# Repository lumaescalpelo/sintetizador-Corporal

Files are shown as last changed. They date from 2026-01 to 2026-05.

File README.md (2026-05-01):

# sintetizador-Corporal
Este proyecto contiene el código y modelos para el proyecto de sintetizador corporal.

## Objetivos
El Sintetizador corporal es un proyecto que consiste en un modulo de sensores conectado via WiFi a una PC que convierte las señales recibidas en notas MIDI y un modulo cámara WiFi que envía posiciones skeleton del cuerpo a un programa secundario para mover un modelo 3D.

## Hardware

Cada modulo corporal contiene los siguientes componentes
- 1 micro controlador ESP32 DevKit V1
- 1 sensor de gas MQ-6
- 1 IMU de 9 ejes ICM-20948V2
- 1 Sensor ambiental ENS160 + AHT2X
- 2 Sensor de efecto Hall 49E

- 1 Base Prototipo.stl
- 1 Tapa.stl
- 1 Strap Holder.stl

- 18 tornillos M3x6
- 1 PowerBank 1Hora 5000mAh

Adicionalmente, cada mano cuenta con los siguientes componentes.
- Hand Circuit.stl
- Strap Holder.stl
- Wrist Strap.stl

Para hacer la detección corporal se usa lo siguiente

- 1 ESP32CAM
- Carcasa ESP32CAM

Para realizar las conexiones se requiere:
- 1 WiFi Modem

Para correr el Software se requiere:
- 1 Equipo PC/MAC

### Direcciones I2C

Los sensores cuentan con las siguientes direcciones I2C

```
ENS160 + AHT2X

ENS160
0x52 → ADDR a GND
0x53 → ADDR a VCC

AHT20 / AHT21 (AHT2X)
0x38 → fija, no configurable

ICM-20948

IMU principal
0x68 → AD0 a GND
0x69 → AD0 a VCC

Magnetómetro interno (AK09916)
0x0C
```

## Software

Este proyecto requiere una colección de software necesaria para el funcionamiento de todos sus sistemas. Debido a que puede instalarse en multiples sistemas operativos y plataformas, se enlaza la documentación oficial de cada software. Las pruebas fueron realizadas en Fedora 43. Las versiones de los softwares utilizados se indican en cada etapa.

- [Arduino IDE](https://www.arduino.cc/en/software/). Probado con la versión 2.3.7
- [ESP32 para Arduino IDE](https://docs.espressif.com/projects/arduino-esp32/en/latest/installing.html). Probado con la versón 2.0.18-arduino.5
- [Node.JS](https://nodejs.org/en/download). Probado con la versión 24.13.1 LTS
- [NPM](https://docs.npmjs.com/downloading-and-installing-node-js-and-npm). Probado con la versión 11.8.0
- [Node-Red](https://nodered.org/docs/getting-started/local). Probado con la versión 4.1.5
- [Mosquitto](https://mosquitto.org/download/). Probado con la versión 2.0.22

Consulta cada carpeta correspondiente a cada software para verificar configuraciones específicas.

## Operar el sintetizador

Para operar el sintetizador corporal se deben seguir los siguientes pasos:

- Abrir Símbolo del sistema
- Ejecutar comando node-red
- Abrir localhost:1880 en cualquier navegador
- Contectar todos los equipos a la misma red
- Abrir otro símbolo del sistema
- Ejecutar el comando ipconfig
- Verificar que el flow en node-red tiene la ip del servidor mosquitto
- Si es en la misma computadora debe ser `localhost` o `127.0.0.1`

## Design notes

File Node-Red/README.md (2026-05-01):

# Node-Red

Este documento contiene las instrucciones para la operación de Node-Red.

## Requisitos

- Node.JS
- NPM
- Node-Red

Para iniciar el servidor, ejecuta el comando `node-red` en una terminal y mantén la terminal abierta durante el periodo de operación. Para correr node-red, asegurate de tener el directorio de instalación agregado al path del sistema.

## Nodos externos

Este proyecto necesita los siguientes nodos externos, los cuales puedes descargar gratuitamente en la sección Manage Palette del botón hamburguesa de Node-Red.

- @flowfuse/node-red-dashboard

## Flows

- **01_Lectura_Básica**. Este flow recibe los datos del programa `Full_MQTT_01`.

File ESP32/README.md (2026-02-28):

# ESP32

Este proyeceto hace uso de un ESP32 Devkit V1 para la lectura de los sensores.

## Bibliotecas

Para correr los programas, se requieren las siguientes bibliotecas.

- ArduinoJson de Benoit Blanchon. Versión probrada 7.4.2
- AHTX0 de Adafruit. Versión probada 2.0.5
- Adafruit Unified Sensor de Adafruit. Versión probada 1.1.15
- PubSubClient de Nick O'Leary. Versión probada 2.8

## Programas de prueba

Se realizaron una serie de programas de prueba para verificar progresivamente el funcionamiento de todos los sensores. Antes de probar estos programas, lee completa la lista, pues la lectura del sensor ENS+AHT se corrige hacia el final debido a que se requieren condiciones específicas de lectura.

Los siguientes programas corresponden a la etapa de desarrollo en la que los sensores analogos tienen su propipo pin, y los acelerómetros y el sensor ambiental comparten 2 buses I2C en los pines 21/22 y en los pines 16/17. En esta etapa, las lecturas del ENS+AHT no reportan correctamente valores.

- **Analog Tester**. Es un programa que realiza la lectura de los sensores magnéticos en los `pines 32 y 35` y la lectura del sensor de gases en el  `pin 34`. Los valores se reportan via monitor serial.
- **I2C Lister**. Es un progama que escanea todas las direcciones I2C usando 2 buses para evitar conflictos con las direcciones I2C de los sensores. Se usan 2 buses porque se usan 2 sensores IMU, uno para cada mano. Los buses se encuentran en los `pines 21 y 22` para el bus A y en los `pines 16 y 17` para el bus B.
- **I2C_Reader_0X**. Son programas que realizan la lectura de todos los sensores por diferentes métodos.
- **Full_Reader_01**. Es un programa que realiza la lectura de los sensores analógicos y digitales y reporta todos los valores vía Serial.
- **Full_MQTT_01**. Es un programa que realiza la lectura de todos los sensores y la reporta en un mensaje MQTT separado por comas al tema `sinte/cuerpo1`. Los datos se envían a una IP fija y a una red predeterminada, estos deben actualizarse en caso de cambiar de configuración.

Los siguientes programas corresponden a la etapa de desarrollo en la que se agrega un tercer bus específico para el sensor ENS+AHT en un bus separado en los pines 25/26.

- **ENS_AHT_Tester**. Es un programa que realiza sólo la lectura del sensor ENS+AHT para garantizar su lectura en un tercer bus.
- **Full_MQTT_02**. Este programa realiza la lectura de todos los sensores y corrige el problema de lectura del ENS+AHT que ahora se encuentra en un tercer bus separado. Este cambio se debe a que este sensor requiere condiciones específicas de lectura.
- **Full_MQTT_03**. Este programa envía los valores con punto decimar ajustado para simplificar el envío.

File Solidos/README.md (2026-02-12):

# Solidos

Este documento detalla la información de los solidos necesarios para este proyecto.

Estos son los archivos que dan soporte al dispositivo Sintetizador Corporal. El dispositivo Wearable en realidad solo es un modulo de sensores que recopila información y la envía por OSC, la solución de sonido y la solución de sintetizador pueden ser ajustadas en un equipo PC o Mac donde se reciban los datos.

Cada modulo corporal contiene los siguientes componentes
- 1 micro controlador ESP32 DevKit V1
- 1 sensor de gas MQ-6
- 1 IMU de 9 ejes ICM-20948V2
- 1 Sensor ambiental ENS160 + AHT2X
- 2 Sensor de efecto Hall 49E

- 1 Base Prototipo.stl
- 1 Tapa.stl
- 1 Strap Holder.stl

- 18 tornillos M3x6
- 1 PowerBank 1Hora 5000mAh

Adicionalmente, cada mano cuenta con los siguientes componentes.
- Hand Circuit.stl
- Strap Holder.stl
- Wrist Strap.stl

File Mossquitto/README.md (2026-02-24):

# Mosquitto

Este proyecto usa el broker MQTT Mosquitto para lograr realizar el intercambio de mensajes entre los dispositivos Sintetizador Corporal y los equipos PC/Mac involucrados en el funcionamiento general.

## Configuraciones

Para que un servidor de mosquitto funcione correctamente, debe permitir conexiones desde IPs externas.

Agrega lo siguiente al archivo `/etc/mosquitto/conf.d/remote.conf`

```
allow_anonymous false
listener 1883 0.0.0.0
```

Asegurate de abrir el puerto 1883 para conexiones TCP y UDP.

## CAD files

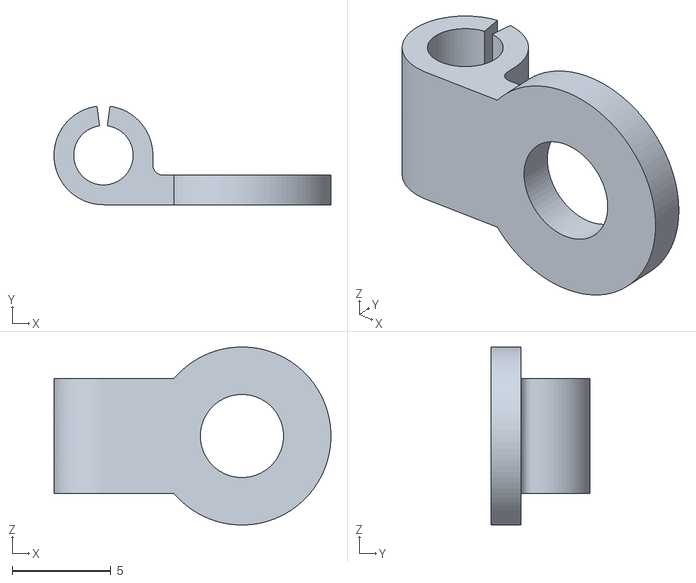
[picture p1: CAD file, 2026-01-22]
Solidos/Clip 2.stl
14.0 x 4.98 x 8.99

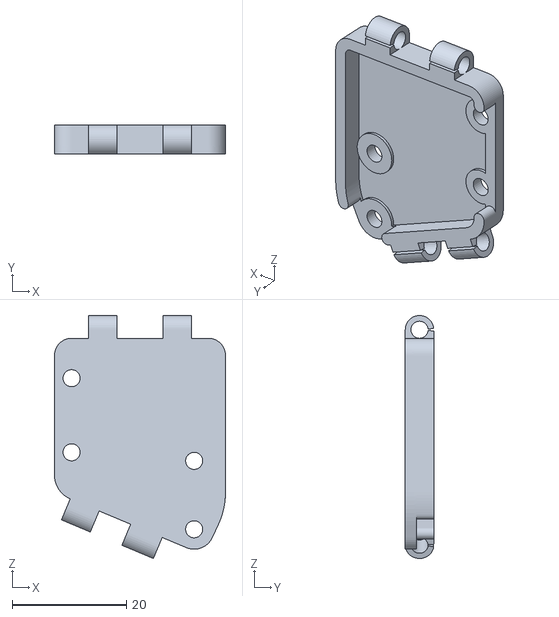
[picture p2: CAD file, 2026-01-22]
Solidos/Hand Circuit.stl
30.0 x 5.00 x 42.6

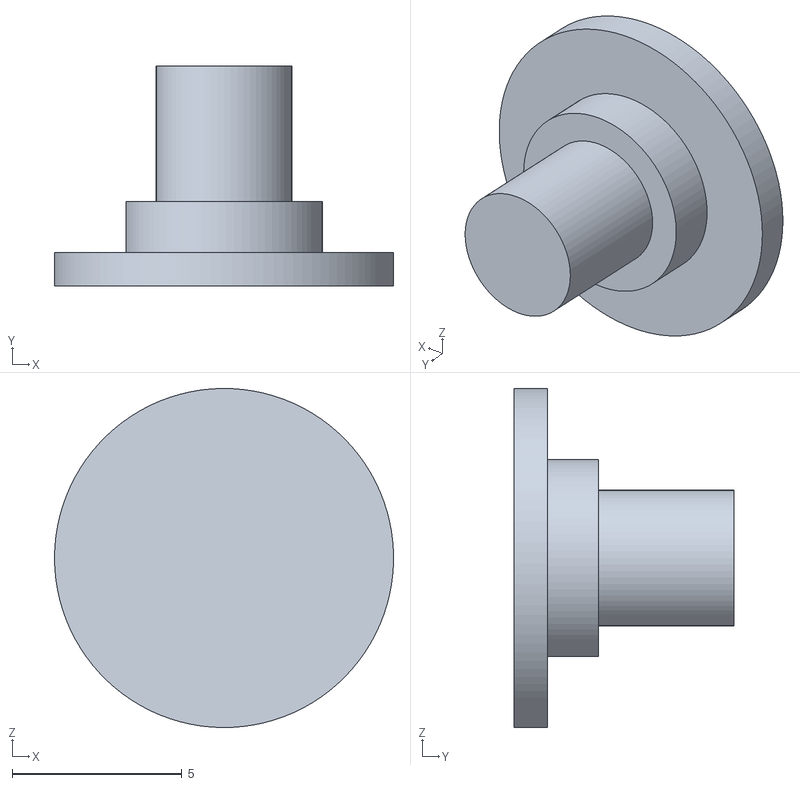
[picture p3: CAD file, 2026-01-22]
Solidos/Clip 1.stl
10.00 x 6.50 x 10.00

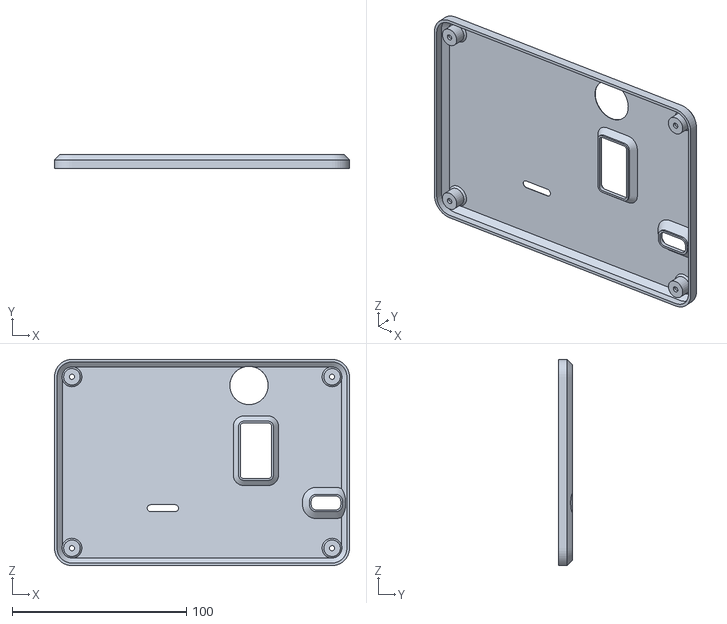
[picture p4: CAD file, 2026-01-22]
Solidos/Tapa.stl
169.5 x 8.00 x 118.5

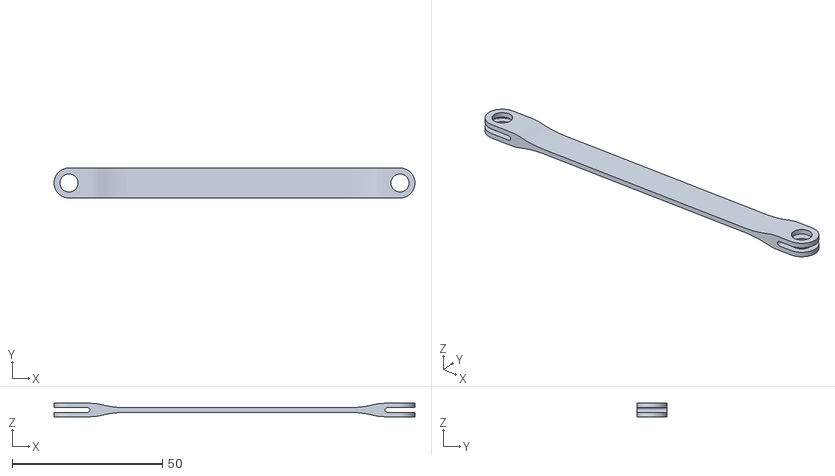
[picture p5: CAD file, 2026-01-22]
Solidos/Wrist Strap.stl
120.0 x 10.0 x 4.50

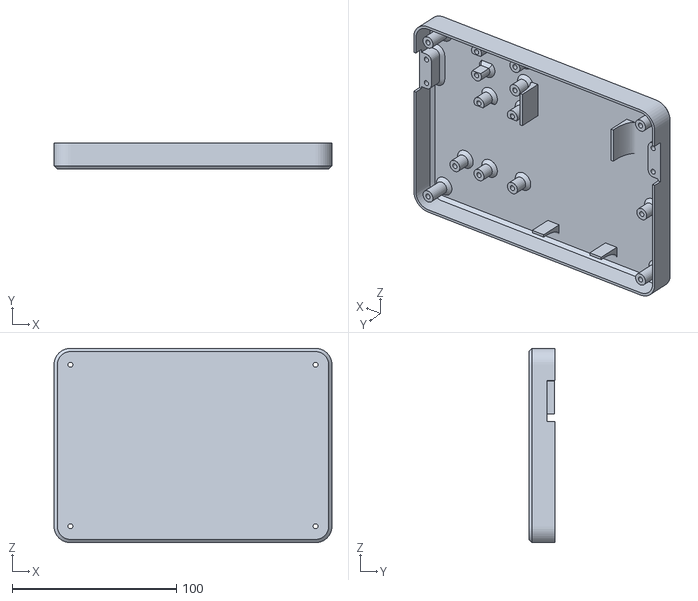
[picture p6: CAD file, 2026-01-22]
Solidos/Base Prototipo.stl
169.5 x 16.0 x 118.5

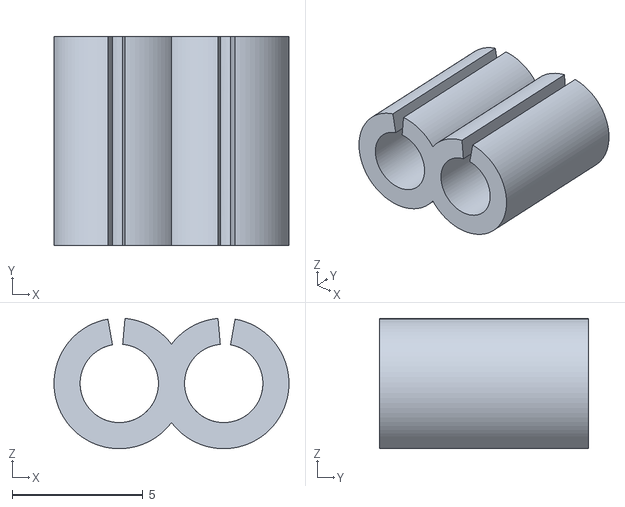
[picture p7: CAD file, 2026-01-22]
Solidos/Strap Holder.stl
9.00 x 8.00 x 4.99

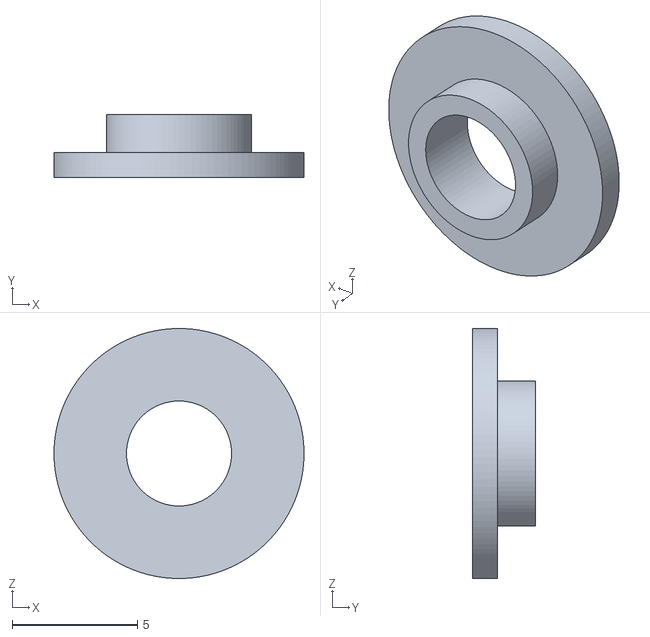
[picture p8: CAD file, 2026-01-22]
Solidos/Clip 3.stl
10.00 x 2.50 x 10.00

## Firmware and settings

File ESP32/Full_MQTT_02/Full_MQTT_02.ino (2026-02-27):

#include <Wire.h>
#include <WiFi.h>
#include <PubSubClient.h>
#include <ArduinoJson.h>

// ================= WiFi / MQTT =================
static const char* WIFI_SSID = "INFINITUMD2AC";
static const char* WIFI_PASS = "PCwGdtcV9D";

static const char* MQTT_HOST = "192.168.1.100";
static const uint16_t MQTT_PORT = 1883;
static const char* MQTT_TOPIC = "sinte/cuerpo1";

WiFiClient espClient;
PubSubClient mqtt(espClient);

// ================= I2C Pines (Hardware) =================
#define SDA_A 21
#define SCL_A 22
#define SDA_B 16
#define SCL_B 17

TwoWire I2C_B = TwoWire(1);

// ================= I2C Pines (Software BUS C) =================
#define SDA_C 25
#define SCL_C 26

// ================= ADC Pines =================
static const int PIN_HALL_32 = 32; // 49E
static const int PIN_MQ6_34  = 34; // MQ-6
static const int PIN_HALL_35 = 35; // 49E

// ================= IMUInfo =================
struct IMUInfo {
  bool present = false;
  bool isMPU6050 = false;
  bool isICM20948 = false;
  uint8_t addr = 0;
};

// ============================================================
//                   Helpers I2C (Hardware)
// ============================================================
bool write8(TwoWire &bus, uint8_t addr, uint8_t reg, uint8_t val) {
  bus.beginTransmission(addr);
  bus.write(reg);
  bus.write(val);
  return bus.endTransmission() == 0;
}

bool readN(TwoWire &bus, uint8_t addr, uint8_t reg, uint8_t *buf, size_t n) {
  bus.beginTransmission(addr);
  bus.write(reg);
  if (bus.endTransmission(false) != 0) return false;
  if (bus.requestFrom((int)addr, (int)n) != (int)n) return false;
  for (size_t i = 0; i < n; i++) buf[i] = bus.read();
  return true;
}

bool read8(TwoWire &bus, uint8_t addr, uint8_t reg, uint8_t &val) {
  return readN(bus, addr, reg, &val, 1);
}

bool ping(TwoWire &bus, uint8_t addr) {
  bus.beginTransmission(addr);
  return (bus.endTransmission() == 0);
}

// ============================================================
//                 Software I2C (BUS C) Bitbang
// ============================================================
// Bitbang súper simple: START/STOP/WRITE/READ con delays.
// Suficiente para AHT2x + ENS160 en bus dedicado.

static inline void i2cDelay() {
  // Ajusta si hace falta: más delay = más confiable (pero más lento)
  delayMicroseconds(6); // ~80-100kHz "aprox" según overhead
}

static inline void sdaHi() { pinMode(SDA_C, INPUT_PULLUP); }
static inline void sdaLo() { pinMode(SDA_C, OUTPUT); digitalWrite(SDA_C, LOW); }

static inline void sclHi() { pinMode(SCL_C, INPUT_PULLUP); }
static inline void sclLo() { pinMode(SCL_C, OUTPUT); digitalWrite(SCL_C, LOW); }

static inline bool sdaRead() { return digitalRead(SDA_C); }

void i2cSoftInit() {
  pinMode(SDA_C, INPUT_PULLUP);
  pinMode(SCL_C, INPUT_PULLUP);
  // idle high
}

void i2cSoftStart() {
  sdaHi(); sclHi(); i2cDelay();
  sdaLo(); i2cDelay();
  sclLo(); i2cDelay();
}

void i2cSoftStop() {
  sdaLo(); i2cDelay();
  sclHi(); i2cDelay();
  sdaHi(); i2cDelay();
}

// Devuelve true si el esclavo ACK
bool i2cSoftWriteByte(uint8_t b) {
  for (int i = 0; i < 8; i++) {
    if (b & 0x80) sdaHi(); else sdaLo();
    i2cDelay();
    sclHi(); i2cDelay();
    sclLo(); i2cDelay();
    b <<= 1;
  }
  // ACK bit
  sdaHi();
  i2cDelay();
  sclHi(); i2cDelay();
  bool ack = (sdaRead() == 0);
  sclLo(); i2cDelay();
  return ack;
}

uint8_t i2cSoftReadByte(bool ack) {
  uint8_t b = 0;
  sdaHi(); // release
  for (int i = 0; i < 8; i++) {
    b <<= 1;
    sclHi(); i2cDelay();
    if (sdaRead()) b |= 1;
    sclLo(); i2cDelay();
  }
  // Send ACK/NACK
  if (ack) sdaLo(); else sdaHi();
  i2cDelay();
  sclHi(); i2cDelay();
  sclLo(); i2cDelay();
  sdaHi();
  return b;
}

bool i2cSoftPing(uint8_t addr7) {
  i2cSoftStart();
  bool ok = i2cSoftWriteByte((addr7 << 1) | 0); // write
  i2cSoftStop();
  return ok;
}

bool i2cSoftWriteReg(uint8_t addr7, uint8_t reg, uint8_t val) {
  i2cSoftStart();
  if (!i2cSoftWriteByte((addr7 << 1) | 0)) { i2cSoftStop(); return false; }
  if (!i2cSoftWriteByte(reg))             { i2cSoftStop(); return false; }
  if (!i2cSoftWriteByte(val))             { i2cSoftStop(); return false; }
  i2cSoftStop();
  return true;
}

bool i2cSoftWriteBytes(uint8_t addr7, const uint8_t *data, size_t n) {
  i2cSoftStart();
  if (!i2cSoftWriteByte((addr7 << 1) | 0)) { i2cSoftStop(); return false; }
  for (size_t i = 0; i < n; i++) {
    if (!i2cSoftWriteByte(data[i])) { i2cSoftStop(); return false; }
  }
  i2cSoftStop();
  return true;
}

bool i2cSoftReadRegN(uint8_t addr7, uint8_t reg, uint8_t *buf, size_t n) {
  i2cSoftStart();
  if (!i2cSoftWriteByte((addr7 << 1) | 0)) { i2cSoftStop(); return false; }
  if (!i2cSoftWriteByte(reg))             { i2cSoftStop(); return false; }

  i2cSoftStart();
  if (!i2cSoftWriteByte((addr7 << 1) | 1)) { i2cSoftStop(); return false; }

  for (size_t i = 0; i < n; i++) {
    buf[i] = i2cSoftReadByte(i + 1 < n); // ACK excepto el último
  }
  i2cSoftStop();
  return true;
}

// ============================================================
//                    AHT2x (BUS C software)
// ============================================================
static const uint8_t AHT_ADDR = 0x38;

bool ahtC_soft_reset() { return i2cSoftWriteReg(AHT_ADDR, 0xBA, 0x00); }

bool ahtC_init() {
  if (!i2cSoftPing(AHT_ADDR)) return false;
  uint8_t cmd[3] = {0xBE, 0x08, 0x00};
  bool ok = i2cSoftWriteBytes(AHT_ADDR, cmd, 3);
  delay(20);
  return ok;
}

bool ahtC_read(float &tempC, float &rh) {
  if (!i2cSoftPing(AHT_ADDR)) return false;

  uint8_t trig[3] = {0xAC, 0x33, 0x00};
  if (!i2cSoftWriteBytes(AHT_ADDR, trig, 3)) return false;

  delay(80);

  uint8_t data[6];
  if (!i2cSoftReadRegN(AHT_ADDR, 0x00, data, 6)) return false;
  if (data[0] & 0x80) return false;

  uint32_t rawHum = ((uint32_t)(data[1]) << 12) | ((uint32_t)(data[2]) << 4) | ((data[3] >> 4) & 0x0F);
  uint32_t rawTmp = ((uint32_t)(data[3] & 0x0F) << 16) | ((uint32_t)(data[4]) << 8) | data[5];

  rh = (rawHum * 100.0f) / 1048576.0f;
  tempC = ((rawTmp * 200.0f) / 1048576.0f) - 50.0f;
  return true;
}

// ============================================================
//                    ENS160 (BUS C software)
// ============================================================
uint8_t ensC_find_addr() {
  if (i2cSoftPing(0x52)) return 0x52;
  if (i2cSoftPing(0x53)) return 0x53;
  return 0x00;
}

bool ensC_init(uint8_t addr) {
  if (!addr) return false;
  // Clear general purpose? (como tu bare-metal)
  i2cSoftWriteReg(addr, 0x12, 0x00);
  delay(20);
  // OPMODE = 0x02 (STANDARD)
  if (!i2cSoftWriteReg(addr, 0x10, 0x02)) return false;
  delay(50);
  return true;
}

bool ensC_read_basic(uint8_t addr, uint8_t &aqi, uint16_t &tvoc, uint16_t &eco2, uint8_t &flags) {
  if (!addr) return false;

  uint8_t b;
  uint8_t buf2[2];

  if (!i2cSoftReadRegN(addr, 0x21, &b, 1)) return false;
  aqi = b;

  if (!i2cSoftReadRegN(addr, 0x22, buf2, 2)) return false;
  tvoc = (uint16_t)buf2[1] << 8 | buf2[0];

  if (!i2cSoftReadRegN(addr, 0x24, buf2, 2)) return false;
  eco2 = (uint16_t)buf2[1] << 8 | buf2[0];

  if (!i2cSoftReadRegN(addr, 0x28, &b, 1)) return false;
  flags = b;

  return true;
}

// ============================================================
//                    MPU-6050 / ICM (hardware)
// ============================================================
bool mpu_init(TwoWire &bus, uint8_t addr) {
  if (!write8(bus, addr, 0x6B, 0x00)) return false;
  delay(10);
  write8(bus, addr, 0x1B, 0x00);
  write8(bus, addr, 0x1C, 0x00);
  return true;
}

bool mpu_read_ag(TwoWire &bus, uint8_t addr, float &ax_g, float &ay_g, float &az_g,
                 float &gx_dps, float &gy_dps, float &gz_dps) {
  uint8_t buf[14];
  if (!readN(bus, addr, 0x3B, buf, 14)) return false;

  int16_t ax = (int16_t)((buf[0] << 8) | buf[1]);
  int16_t ay = (int16_t)((buf[2] << 8) | buf[3]);
  int16_t az = (int16_t)((buf[4] << 8) | buf[5]);
  int16_t gx = (int16_t)((buf[8] << 8) | buf[9]);
  int16_t gy = (int16_t)((buf[10] << 8) | buf[11]);
  int16_t gz = (int16_t)((buf[12] << 8) | buf[13]);

  ax_g = ax / 16384.0f;
  ay_g = ay / 16384.0f;
  az_g = az / 16384.0f;
  gx_dps = gx / 131.0f;
  gy_dps = gy / 131.0f;
  gz_dps = gz / 131.0f;
  return true;
}

bool icm_select_bank(TwoWire &bus, uint8_t addr, uint8_t bank) {
  return write8(bus, addr, 0x7F, (bank << 4));
}

bool icm_init(TwoWire &bus, uint8_t addr) {
  if (!icm_select_bank(bus, addr, 0)) return false;
  write8(bus, addr, 0x06, 0x01);
  delay(10);
  return true;
}

bool icm_read_ag(TwoWire &bus, uint8_t addr, float &ax_g, float &ay_g, float &az_g,
                 float &gx_dps, float &gy_dps, float &gz_dps) {
  if (!icm_select_bank(bus, addr, 0)) return false;
  uint8_t bufA[6], bufG[6];
  if (!readN(bus, addr, 0x2D, bufA, 6)) return false;
  if (!readN(bus, addr, 0x33, bufG, 6)) return false;

  int16_t ax = (int16_t)((bufA[0] << 8) | bufA[1]);
  int16_t ay = (int16_t)((bufA[2] << 8) | bufA[3]);
  int16_t az = (int16_t)((bufA[4] << 8) | bufA[5]);

  int16_t gx = (int16_t)((bufG[0] << 8) | bufG[1]);
  int16_t gy = (int16_t)((bufG[2] << 8) | bufG[3]);
  int16_t gz = (int16_t)((bufG[4] << 8) | bufG[5]);

  ax_g = ax / 16384.0f;
  ay_g = ay / 16384.0f;
  az_g = az / 16384.0f;
  gx_dps = gx / 131.0f;
  gy_dps = gy / 131.0f;
  gz_dps = gz / 131.0f;
  return true;
}

IMUInfo detectIMU(TwoWire &bus, uint8_t addr) {
  IMUInfo info;
  info.addr = addr;

  if (!ping(bus, addr)) return info;

  uint8_t who_mpu;
  if (read8(bus, addr, 0x75, who_mpu)) {
    if (who_mpu == 0x68 || who_mpu == 0x69) {
      info.present = true;
      info.isMPU6050 = true;
      return info;
    }
  }

  uint8_t who_icm;
  if (read8(bus, addr, 0x00, who_icm)) {
    if (who_icm == 0xEA) {
      info.present = true;
      info.isICM20948 = true;
      return info;
    }
  }

  info.present = true; // presente pero desconocido
  return info;
}

// ============================================================
//                    ADC / WiFi / MQTT
// ============================================================
float adc_to_volts(int raw, float vref = 3.3f) { return (raw * vref) / 4095.0f; }

void wifiConnect() {
  WiFi.mode(WIFI_STA);
  WiFi.setSleep(false);
  WiFi.begin(WIFI_SSID, WIFI_PASS);

  uint32_t t0 = millis();
  while (WiFi.status() != WL_CONNECTED) {
    delay(250);
    if (millis() - t0 > 20000) {
      WiFi.disconnect(true);
      delay(500);
      WiFi.begin(WIFI_SSID, WIFI_PASS);
      t0 = millis();
    }
  }
}

void mqttConnect() {
  mqtt.setServer(MQTT_HOST, MQTT_PORT);
  mqtt.setKeepAlive(30);
  mqtt.setSocketTimeout(5);
  // Para payloads grandes
  mqtt.setBufferSize(1024);

  while (!mqtt.connected()) {
    uint32_t chip = (uint32_t)(ESP.getEfuseMac() & 0xFFFFFF);
    char clientId[24];
    snprintf(clientId, sizeof(clientId), "cuerpo1-%06lX", (unsigned long)chip);
    if (!mqtt.connect(clientId)) delay(1000);
  }
}

// ============================================================
//                          Setup / Loop
// ============================================================
static uint8_t ensC_addr = 0;
static bool ensC_ready = false;

void setup() {
  Serial.begin(115200);
  delay(400);

  // Hardware I2C
  Wire.begin(SDA_A, SCL_A);
  Wire.setClock(400000);

  I2C_B.begin(SDA_B, SCL_B);
  I2C_B.setClock(400000);

  // Software I2C (BUS C)
  i2cSoftInit();
  delay(10);

  // ADC config
  analogReadResolution(12);
  analogSetAttenuation(ADC_11db);
  analogSetPinAttenuation(PIN_HALL_32, ADC_11db);
  analogSetPinAttenuation(PIN_MQ6_34,  ADC_11db);
  analogSetPinAttenuation(PIN_HALL_35, ADC_11db);

  // Init AHT+ENS en BUS C (soft)
  Serial.println("\nI2C ping (BUS C soft):");
  Serial.print("  AHT 0x38: "); Serial.println(i2cSoftPing(0x38) ? "OK" : "NO");
  Serial.print("  ENS 0x52: "); Serial.println(i2cSoftPing(0x52) ? "OK" : "NO");
  Serial.print("  ENS 0x53: "); Serial.println(i2cSoftPing(0x53) ? "OK" : "NO");

  if (i2cSoftPing(0x38)) {
    ahtC_soft_reset();
    ahtC_init();
  }

  ensC_addr = ensC_find_addr();
  if (ensC_addr) ensC_ready = ensC_init(ensC_addr);

  // Red
  wifiConnect();
  mqttConnect();

  Serial.println("Full_MQTT (A,B hardware + C software) listo.");
}

void loop() {
  if (WiFi.status() != WL_CONNECTED) wifiConnect();
  if (!mqtt.connected()) mqttConnect();
  mqtt.loop();

  // ===== ADC =====
  int raw32 = analogRead(PIN_HALL_32);
  int raw34 = analogRead(PIN_MQ6_34);
  int raw35 = analogRead(PIN_HALL_35);

  float v32 = adc_to_volts(raw32);
  float v34 = adc_to_volts(raw34);
  float v35 = adc_to_volts(raw35);

  // ===== ENS + AHT en BUS C (software) =====
  float c_t = NAN, c_rh = NAN;
  bool c_aht_ok = ahtC_read(c_t, c_rh);

  // Si ENS no estaba listo, reintenta detectar/init cada cierto tiempo
  if (!ensC_ready) {
    ensC_addr = ensC_find_addr();
    if (ensC_addr) ensC_ready = ensC_init(ensC_addr);
  }

  uint8_t c_aqi = 0, c_flags = 0;
  uint16_t c_tvoc = 0, c_eco2 = 0;
  bool c_ens_ok = false;
  if (ensC_ready) {
    c_ens_ok = ensC_read_basic(ensC_addr, c_aqi, c_tvoc, c_eco2, c_flags);
    // Si falla, marca como no listo para forzar reinit después
    if (!c_ens_ok) ensC_ready = false;
  }

  // ===== IMUs (A/B hardware) =====
  IMUInfo imuA_68 = detectIMU(Wire, 0x68);
  IMUInfo imuA_69 = detectIMU(Wire, 0x69);
  IMUInfo imuB_68 = detectIMU(I2C_B, 0x68);
  IMUInfo imuB_69 = detectIMU(I2C_B, 0x69);

  auto readIMU = [](TwoWire &bus, IMUInfo imu,
                    float &ax, float &ay, float &az, float &gx, float &gy, float &gz, bool &ok) {
    ax = ay = az = gx = gy = gz = NAN;
    ok = false;
    if (!imu.present) return;

    if (imu.isMPU6050) {
      mpu_init(bus, imu.addr);
      ok = mpu_read_ag(bus, imu.addr, ax, ay, az, gx, gy, gz);
    } else if (imu.isICM20948) {
      icm_init(bus, imu.addr);
      ok = icm_read_ag(bus, imu.addr, ax, ay, az, gx, gy, gz);
    }
  };

  float a68_ax, a68_ay, a68_az, a68_gx, a68_gy, a68_gz; bool a68_ok;
  float a69_ax, a69_ay, a69_az, a69_gx, a69_gy, a69_gz; bool a69_ok;
  float b68_ax, b68_ay, b68_az, b68_gx, b68_gy, b68_gz; bool b68_ok;
  float b69_ax, b69_ay, b69_az, b69_gx, b69_gy, b69_gz; bool b69_ok;

  readIMU(Wire,  imuA_68, a68_ax, a68_ay, a68_az, a68_gx, a68_gy, a68_gz, a68_ok);
  readIMU(Wire,  imuA_69, a69_ax, a69_ay, a69_az, a69_gx, a69_gy, a69_gz, a69_ok);
  readIMU(I2C_B, imuB_68, b68_ax, b68_ay, b68_az, b68_gx, b68_gy, b68_gz, b68_ok);
  readIMU(I2C_B, imuB_69, b69_ax, b69_ay, b69_az, b69_gx, b69_gy, b69_gz, b69_ok);

  // ===== JSON payload =====
  StaticJsonDocument<1024> doc;
  doc["ms"] = (uint32_t)millis();
  doc["device"] = "esp32-cuerpo1";

  JsonObject adc = doc.createNestedObject("adc");
  adc["h32"] = raw32; adc["h32v"] = v32;
  adc["mq6"] = raw34; adc["mq6v"] = v34;
  adc["h35"] = raw35; adc["h35v"] = v35;

  JsonObject aht = doc.createNestedObject("aht");
  JsonObject ahtC = aht.createNestedObject("C");
  if (c_aht_ok) { ahtC["t"] = c_t; ahtC["rh"] = c_rh; }
  else          { ahtC["t"] = nullptr; ahtC["rh"] = nullptr; }

  JsonObject ens = doc.createNestedObject("ens");
  JsonObject ensC = ens.createNestedObject("C");
  if (ensC_addr) ensC["addr"] = ensC_addr; else ensC["addr"] = nullptr;
  if (c_ens_ok) {
    ensC["aqi"] = c_aqi;
    ensC["tvoc"] = c_tvoc;
    ensC["eco2"] = c_eco2;
    ensC["flags"] = c_flags;
  } else {
    ensC["aqi"] = nullptr;
    ensC["tvoc"] = nullptr;
    ensC["eco2"] = nullptr;
    ensC["flags"] = nullptr;
  }

  JsonObject imu = doc.createNestedObject("imu");
  auto imuObj = [&](const char* key, bool ok, float ax, float ay, float az, float gx, float gy, float gz) {
    JsonObject o = imu.createNestedObject(key);
    if (ok) { o["ax"]=ax; o["ay"]=ay; o["az"]=az; o["gx"]=gx; o["gy"]=gy; o["gz"]=gz; }
    else    { o["ax"]=nullptr; o["ay"]=nullptr; o["az"]=nullptr; o["gx"]=nullptr; o["gy"]=nullptr; o["gz"]=nullptr; }
  };

  imuObj("A68", a68_ok, a68_ax, a68_ay, a68_az, a68_gx, a68_gy, a68_gz);
  imuObj("A69", a69_ok, a69_ax, a69_ay, a69_az, a69_gx, a69_gy, a69_gz);
  imuObj("B68", b68_ok, b68_ax, b68_ay, b68_az, b68_gx, b68_gy, b68_gz);
  imuObj("B69", b69_ok, b69_ax, b69_ay, b69_az, b69_gx, b69_gy, b69_gz);

  char payload[1024];
  size_t n = serializeJson(doc, payload, sizeof(payload));

  bool okPub = mqtt.publish(MQTT_TOPIC, payload, n);
  Serial.print(okPub ? "MQTT OK " : "MQTT FAIL ");
  Serial.print("bytes="); Serial.print(n);
  Serial.print(" -> ");
  Serial.println(payload);

  delay(2000);
}

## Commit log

2026-01-22 Solidos agregados
    [Base Prototipo.stl, Clip 1.stl, Clip 2.stl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]
2026-02-24 Flow inicial agregado
2026-02-27 Sensor ENS+AHT corregido
